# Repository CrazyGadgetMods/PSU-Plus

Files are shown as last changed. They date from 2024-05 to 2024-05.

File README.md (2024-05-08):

# PSU-Plus
The PSU-Plus is the spiritual successor to Noah's RVL-PSU, designed for ease of assembly and versatility across many micro-type builds.

Like it's predecessor, the PSU-Plus has 1V, 1.15V, 3.3V and 5V regulators. Where the PSU-Plus differs is the addition of a 1.8V regulator for builds that remove the LDO from the Wii (such as Wesk's GC Micro and the GC Nano).

I designed this board when the TLV62130RGTR regulators were out of stock as a drop-in replacement for the RVL-PSU. It has the exact same board outline dimensions, as well as the same screw hole layout / dimensions.

I have added an additional VIN pad for builds that use VIN elsewhere in the project (such as feeding 12V to the audio amplifier / sensor bar in the Noldendo Miicro). I have also added jumper pads to enable / disable the 1v8 and 5v regulars if your build does not require either of them.

**VIN Min: 5V**\
**VIN Max: 18V**\
**Max current output (per regulator): 3A**

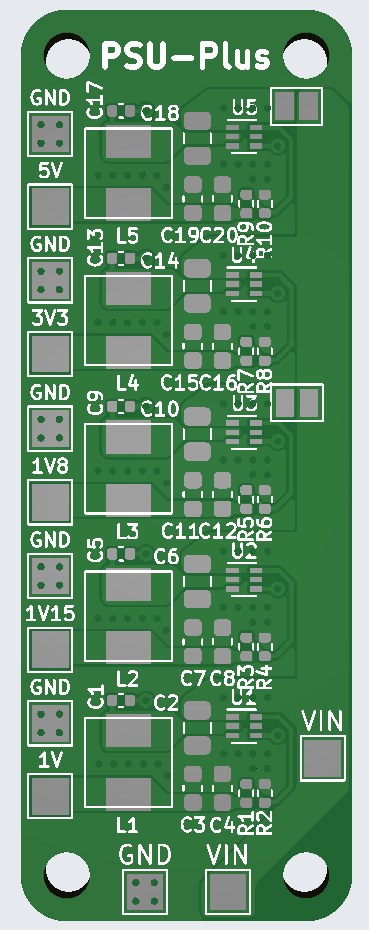
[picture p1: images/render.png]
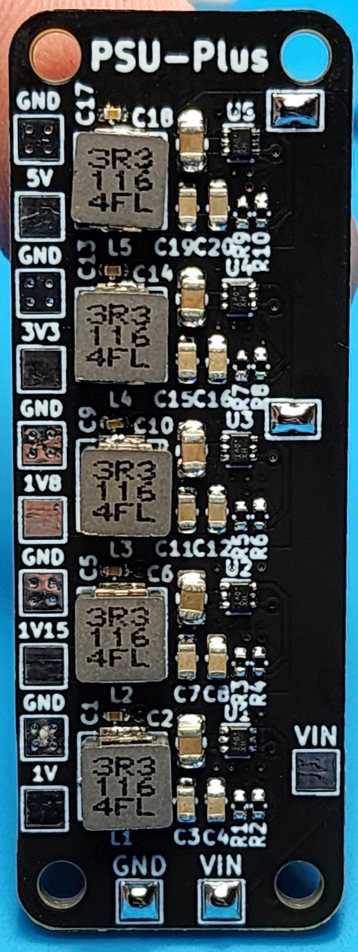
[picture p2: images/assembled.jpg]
 

If you are interested in buying one of these boards pre-assembled, I sell them on my [Etsy Store](https://www.etsy.com/listing/1510321427/psu-plus-power-board-for-wii-micros).

## Credits
- [YveltalGriffin](https://github.com/mackieks): Holding my hand while I did the layout of the board and answering my infinite questions
- [Noah](https://bitbuilt.net/forums/index.php?members/noah.1/): Making the original [RVL-PSU](https://bitbuilt.net/forums/index.php?threads/rvl-psu.3335/)
- [BitBuilt](https://bitbuilt.net/): Being the best modding community out there!

## License
Solderpad Hardware License v2.1

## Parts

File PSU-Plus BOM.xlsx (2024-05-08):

Ref Des | Qty | Manufacturer PN | Digikey PN | Description
U1, U2, U3, U4, U5 | 5 | AP62301Z6-7 | 31-AP62301Z6-7CT-ND | DCDC CONV HV BUCK SOT563 T&R 3K
L1, L2, L3, L4, L5 | 5 | PCMB053T-3R3MS | 408-1520-1-ND | FIXED IND 3.3UH 5A 38 MOHM SMD
C1, C5, C9, C13, C17 | 5 | CL05A104KA5NNNC | 1276-1043-1-ND | CAP CER 0.1UF 25V X5R 0402
C2, C6, C10, C14, C18 | 5 | CL21A106KAYNNNE | 1276-2891-1-ND | CAP CER 10UF 25V X5R 0805
C3, C4, C7, C8, C11, C12, C15, C16, C19, C20 | 10 | CL10A226MP8NUNE | 1276-1274-1-ND | CAP CER 22UF 10V X5R 0603
R2, R4, R6, R8, R10 | 5 | RC0402FR-0710KL | 311-10.0KLRCT-ND | RES 10K OHM 1% 1/16W 0402
R1 | 1 | RC0402FR-072K55L | YAG3102CT-ND | RES 2.55K OHM 1% 1/16W 0402
R3 | 1 | RC0402FR-074K42L | YAG3174CT-ND | RES 4.42K OHM 1% 1/16W 0402
R5 | 1 | RC0402FR-0712K4L | 311-12.4KLRCT-ND | RES 12.4K OHM 1% 1/16W 0402
R7 | 1 | RC0402FR-0731K6L | YAG3115CT-ND | RES 31.6K OHM 1% 1/16W 0402
R9 | 1 | RC0402FR-0752K3L | YAG3179CT-ND | RES 52.3K OHM 1% 1/16W 0402

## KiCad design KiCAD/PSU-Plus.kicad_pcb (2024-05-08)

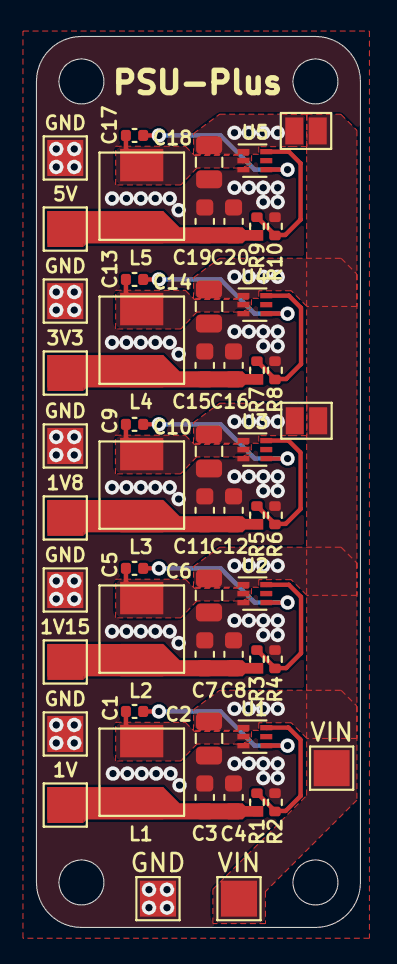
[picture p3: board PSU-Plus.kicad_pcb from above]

Board: 2 copper layers, 18.0 x 49.5 mm, 55 parts (0 on the bottom side), 24 nets.

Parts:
1V: 1v; TestPoint_Pad_2.0x2.0mm
1V8: 1v8; TestPoint_Pad_2.0x2.0mm
1V15: 1v15; TestPoint_Pad_2.0x2.0mm
3V3: 3v3; TestPoint_Pad_2.0x2.0mm
5V: 5v; TestPoint_Pad_2.0x2.0mm
C1, C5, C9, C13, C17: 100nF; C_0402_1005Metric
C2, C6, C10, C14, C18: 10uF; C_0805_2012Metric
C3, C4, C7, C8, C11, C12, C15, C16, C19, C20: 22uF; C_0603_1608Metric
GND: GND; TestPoint_Pad_2.0x2.0mm
GND#2, GND#3, GND#4, GND#5, GND#6: GND; TestPoint_Pad_2.0x2.0mm
JP1, JP2: SolderJumper_2_Open; SolderJumper-2_P1.3mm_Open_Pad1.0x1.5mm
L1, L2, L3, L4, L5: 3.3uH; 1919
R1: 2.55k; R_0402_1005Metric
R2, R4, R6, R8, R10: 10k; R_0402_1005Metric
R3: 4.42k; R_0402_1005Metric
R5: 12.4k; R_0402_1005Metric
R7: 31.6k; R_0402_1005Metric
R9: 52.3k; R_0402_1005Metric
U1, U2, U3, U4, U5: AP62301Z6-7; SOT-563mod
VIN: VIN; TestPoint_Pad_2.0x2.0mm
VIN#2: VIN; TestPoint_Pad_2.0x2.0mm

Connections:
GND: C2.1, C3.2, C4.2, C6.1, C7.2, C8.2, C10.1, C11.2, C12.2, C14.1, C15.2, C16.2, C18.1, C19.2, C20.2, GND.1, GND#2.1, GND#3.1, GND#4.1, GND#5.1, GND#6.1, R2.2, R4.2, R6.2, R8.2, R10.2, U1.3 (GND), U2.3 (GND), U3.3 (GND), U4.3 (GND), U5.3 (GND)
unnamed: C1.1, U1.4 (BST)
unnamed: C1.2, L1.1, U1.2 (SW)
unnamed: 1V.1, C3.1, C4.1, L1.2, R1.1
unnamed: C5.1, U2.4 (BST)
unnamed: C5.2, L2.1, U2.2 (SW)
unnamed: 1V15.1, C7.1, C8.1, L2.2, R3.1
unnamed: C9.1, U3.4 (BST)
unnamed: C9.2, L3.1, U3.2 (SW)
unnamed: C10.2, JP1.2 (B), U3.1 (VIN)
unnamed: 1V8.1, C11.1, C12.1, L3.2, R5.1
unnamed: C13.1, U4.4 (BST)
unnamed: C13.2, L4.1, U4.2 (SW)
unnamed: 3V3.1, C15.1, C16.1, L4.2, R7.1
unnamed: C17.1, U5.4 (BST)
unnamed: C17.2, L5.1, U5.2 (SW)
unnamed: C18.2, JP2.2 (B), U5.1 (VIN)
unnamed: 5V.1, C19.1, C20.1, L5.2, R9.1
unnamed: R1.2, R2.1, U1.6 (FB)
unnamed: R3.2, R4.1, U2.6 (FB)
unnamed: R5.2, R6.1, U3.6 (FB)
unnamed: R7.2, R8.1, U4.6 (FB)
unnamed: R9.2, R10.1, U5.6 (FB)
VIN: C2.2, C6.2, C14.2, JP1.1 (A), JP2.1 (A), U1.1 (VIN), U2.1 (VIN), U4.1 (VIN), VIN.1, VIN#2.1
